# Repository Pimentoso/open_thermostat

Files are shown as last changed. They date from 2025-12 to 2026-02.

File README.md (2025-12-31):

# open_thermostat

A lightweight, open-source thermostat controller. Based on Lolin S2 mini board

## Quickstart

Install
```bash
git clone https://github.com/your-org/open_thermostat.git
cd open_thermostat
python -m venv .venv
source .venv/bin/activate
esphome run open_thermostat.yaml
```

## TODO

- Add 4.7k resistor on temp sensor
- Change button pin to GPIO1–6, GPIO14–18, GPIO21

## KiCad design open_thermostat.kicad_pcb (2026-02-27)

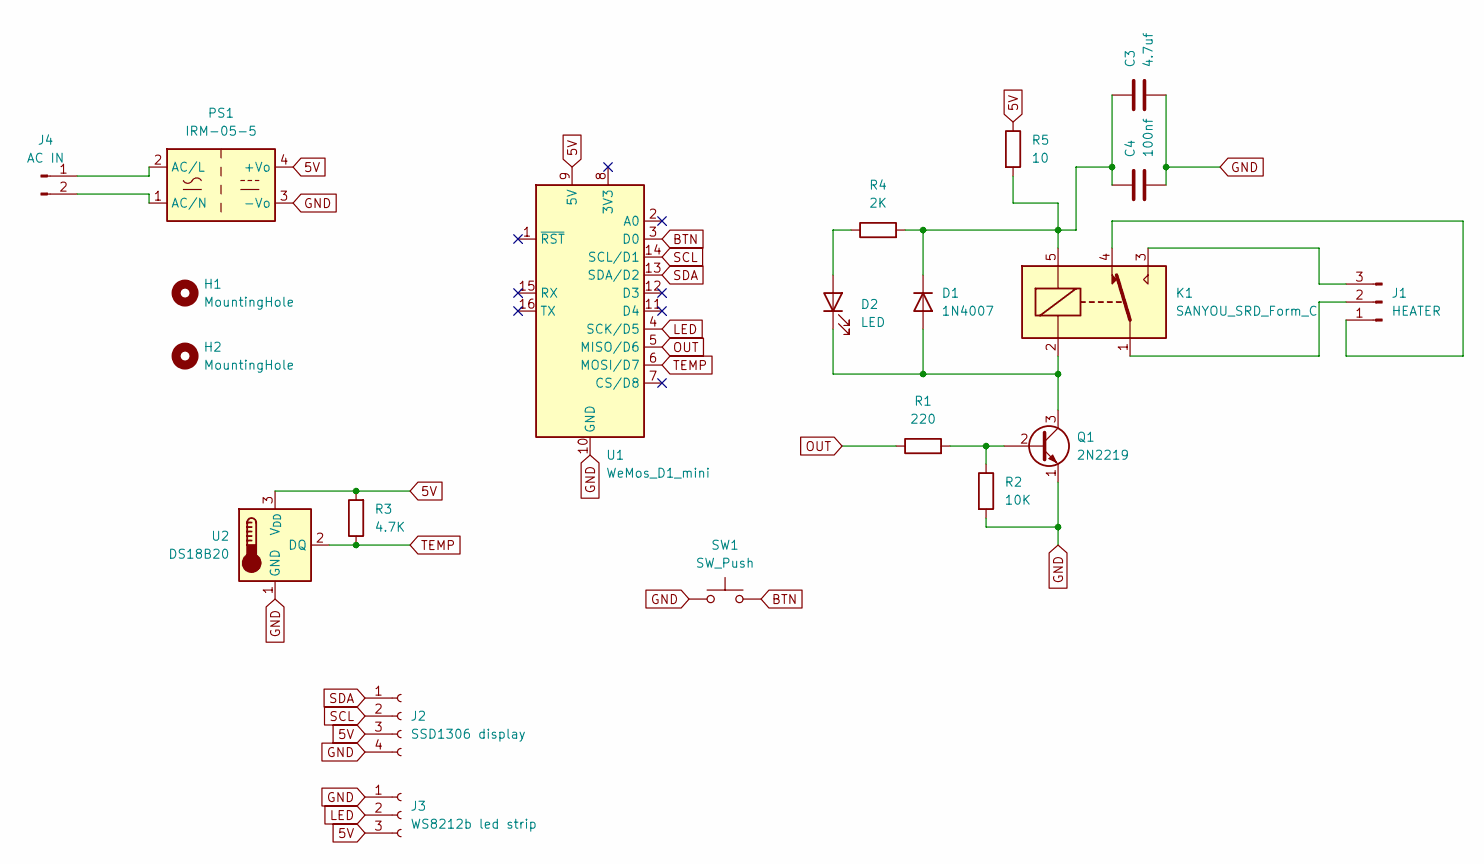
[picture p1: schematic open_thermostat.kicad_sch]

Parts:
C3: 4.7uf; C_1206_3216Metric_Pad1.33x1.80mm_HandSolder
C4: 100nf; C_1206_3216Metric_Pad1.33x1.80mm_HandSolder
D1: 1N4007; D_DO-41_SOD81_P10.16mm_Horizontal
D2: LED; LED_D5.0mm
H1, H2: MountingHole; MountingHole_4.3mm_M4
J1: HEATER; TerminalBlock_MetzConnect_Type094_RT03503HBLU_1x03_P5.00mm_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
J2: SSD1306 display; JST_XH_B4B-XH-A_1x04_P2.50mm_Vertical
J3: WS8212b led strip; JST_XH_B3B-XH-A_1x03_P2.50mm_Vertical
J4: AC IN; TerminalBlock_MetzConnect_Type094_RT03502HBLU_1x02_P5.00mm_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
K1: SANYOU_SRD_Form_C; Relay_SPDT_SANYOU_SRD_Series_Form_C
PS1: IRM-05-5; 220v AC to 5v DC Transformer
Q1: 2N2219; SOT-23_Handsoldering
R1: 220; R_1206_3216Metric_Pad1.30x1.75mm_HandSolder
R2: 10K; R_1206_3216Metric_Pad1.30x1.75mm_HandSolder
R3: 4.7K; R_1206_3216Metric_Pad1.30x1.75mm_HandSolder
R4: 2K; R_1206_3216Metric_Pad1.30x1.75mm_HandSolder
R5: 10; R_1206_3216Metric_Pad1.30x1.75mm_HandSolder
SW1: SW_Push; SW_Push_1P1T_NO_6x6mm_H9.5mm
U1: WeMos_D1_mini; WEMOS_D1_mini_light
U2: DS18B20; TO-92_Inline

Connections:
5V: J2.3, J3.3, PS1.4 (+Vo), R3.2, R5.1, U1.9 (5V), U2.3 (V_{DD})
BTN: SW1.2, U1.3 (D0)
GND: C3.1, C4.1, J2.4, J3.1, PS1.3 (-Vo), Q1.1 (E), R2.2, SW1.1, U1.10 (GND), U2.1 (GND)
LED: J3.2, U1.4 (SCK/D5)
unnamed: D1.2 (A), D2.1 (K), K1.2, Q1.3 (C)
unnamed: C3.2, C4.2, D1.1 (K), K1.5, R4.2, R5.2
unnamed: D2.2 (A), R4.1
unnamed: J1.1, K1.4
unnamed: J1.2, K1.1
unnamed: J1.3, K1.3
unnamed: J4.1, PS1.2 (AC/L)
unnamed: J4.2, PS1.1 (AC/N)
unnamed: Q1.2 (B), R1.2, R2.1
OUT: R1.1, U1.5 (MISO/D6)
SCL: J2.2, U1.14 (SCL/D1)
SDA: J2.1, U1.13 (SDA/D2)
TEMP: R3.1, U1.6 (MOSI/D7), U2.2 (DQ)

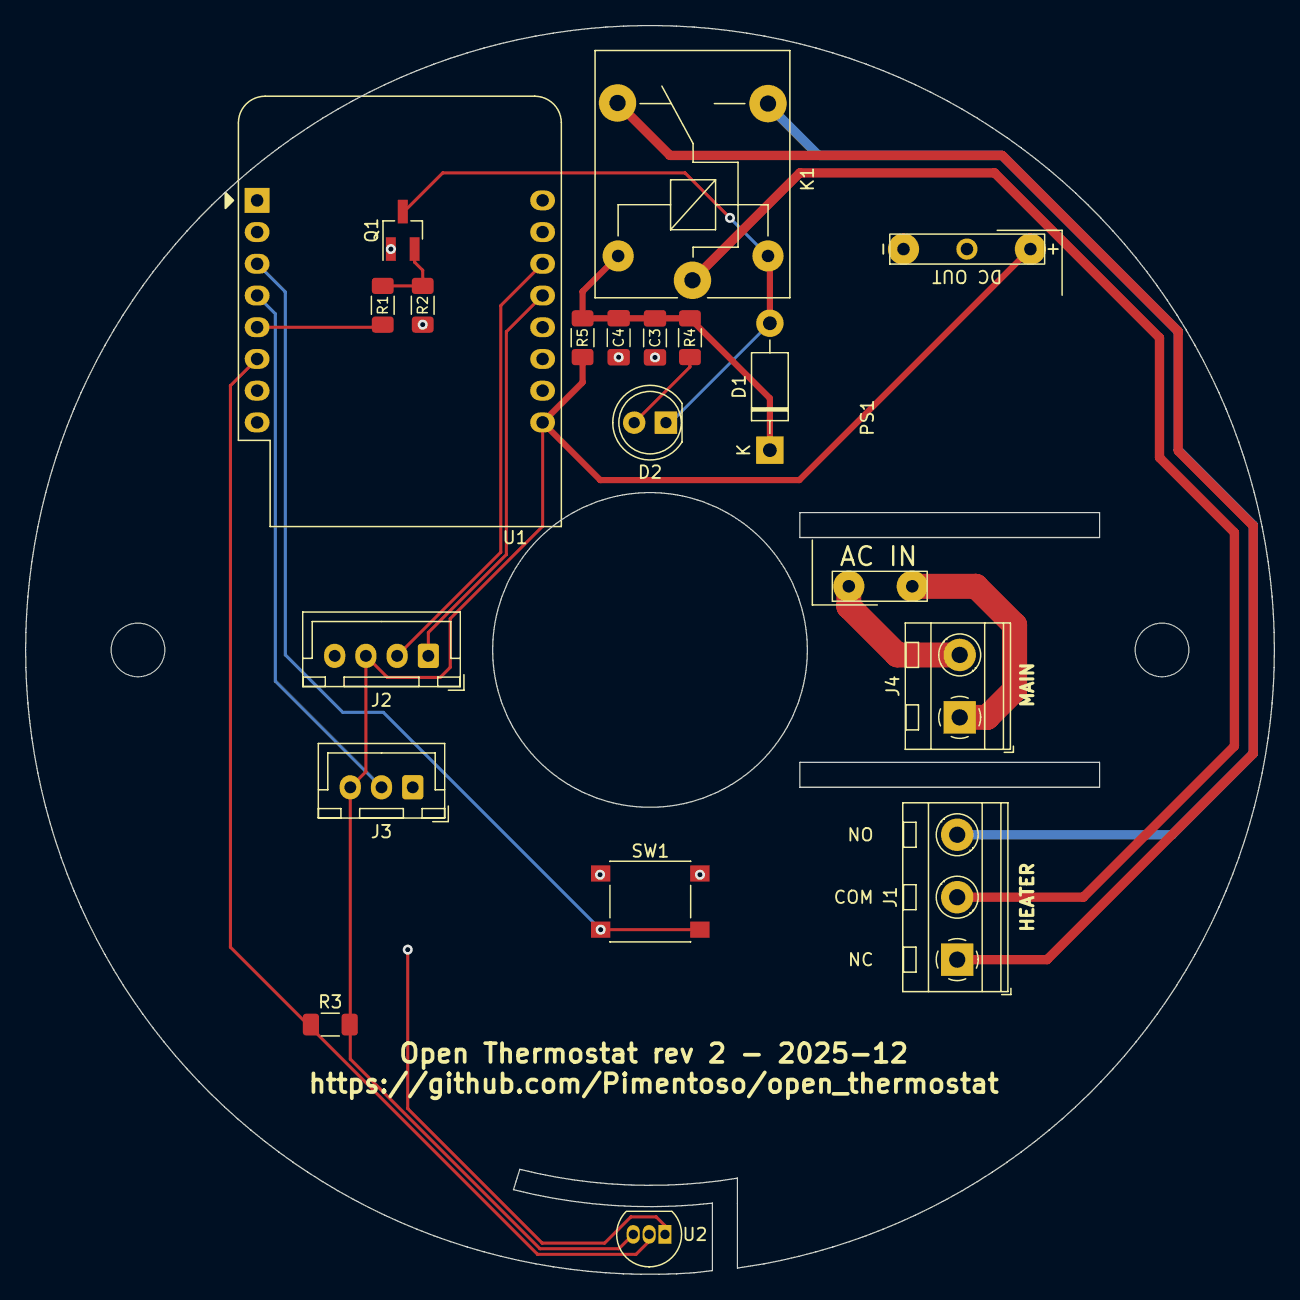
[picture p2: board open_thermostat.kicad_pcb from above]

Board: 2 copper layers, 100.0 x 100.0 mm, 21 parts (0 on the bottom side), 17 nets.

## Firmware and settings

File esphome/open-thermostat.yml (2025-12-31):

substitutions:
  device_name: open-thermostat
  day_temp: "19.5"
  night_temp: "17.0"

esphome:
  name: ${device_name}

esp32:
  board: lolin_s2_mini
  variant: esp32s2
  framework:
    type: esp-idf

preferences:
  flash_write_interval: 10min

wifi:
  ssid: !secret wifi_ssid
  password: !secret wifi_password
  power_save_mode: none
  ap:
    ssid: ${device_name} hotspot
    password: !secret hotspot_password

captive_portal:

logger:
  baud_rate: 0

api:

ota:
  platform: esphome

i2c:
  scl: GPIO35
  sda: GPIO33
  scan: true
  
one_wire:
- platform: gpio
  pin: GPIO12
  
switch:
- platform: gpio
  pin: GPIO9
  name: "${device_name}-relay"
  id: relay_caldaia
  restore_mode: RESTORE_DEFAULT_OFF
  on_turn_on:
    - delay: 200ms
    - light.turn_on:
        id: rgb_leds
        red: 100%
        green: 40%
        blue: 0%
        effect: circle
  on_turn_off:
    - delay: 200ms
    - light.turn_off: rgb_leds
  
binary_sensor:
- platform: gpio
  pin:
    number: GPIO11
    mode: INPUT_PULLUP
    inverted: true
  name: "${device_name}-toggle"
  id: toggle_button
  internal: true
  on_press:
    - switch.toggle: relay_caldaia
  filters:
    - delayed_on_off: 50ms

sensor:
- platform: dallas_temp
  name: "${device_name}-temperature"
  id: temperature_sensor
  device_class: temperature
  state_class: measurement
  unit_of_measurement: "°C"
  accuracy_decimals: 1
  update_interval: 30s
  filters:
    - sliding_window_moving_average:
        window_size: 12
        send_every: 4
        send_first_at: 1

button:
- platform: restart
  name: "${device_name}-restart"
  entity_category: config
- platform: factory_reset
  name: "${device_name}-factory-reset"
  id: Reset
  entity_category: config
- platform: safe_mode
  name: "${device_name}-safe-mode"
  internal: false
  entity_category: config

light:
- platform: esp32_rmt_led_strip
  pin: GPIO7
  name: "${device_name}-leds"
  id: rgb_leds
  chipset: WS2812
  rgb_order: GRB
  num_leds: 24
  color_correct: [25%, 25%, 25%]
  effects:
  - addressable_lambda:
      name: circle
      update_interval: 500ms
      lambda: |-
        static int pos = 0;
        int len = it.size();
        // clear strip
        for (int i = 0; i < len; i++) it[i] = Color(0, 0, 0);
        // light 3 consecutive LEDs (unidirectional)
        for (int j = 0; j < 3; j++) {
          it[(pos + j) % len] = Color(255, 100, 0);
        }
        pos = (pos + 1) % len;
- platform: status_led
  name: "${device_name}-status-led"
  icon: "mdi:alarm-light"
  restore_mode: ALWAYS_OFF
  pin:
    number: GPIO15
    inverted: false

globals:
- id: jitter
  type: int
  restore_value: no
  initial_value: '0'
- id: jitter_temp
  type: int
  restore_value: no
  initial_value: '10'

# Anti burn-in
interval:
- interval: 3s
  then:
    - lambda: |-
        id(jitter) = (id(jitter) + 1) % 3;
        id(jitter_temp) = (id(jitter_temp) + 1) % 20;

display:
- platform: ssd1306_i2c
  id: oled_display
  model: SSD1306 128x64
  address: 0x3C
  rotation: 180
  pages:
    - id: display_page_1
      lambda: |-
        it.fill(COLOR_OFF);
        const int xoff = id(jitter);
        const int xoff_temp = id(jitter_temp);

        // TIME — small, top-left
        it.strftime(2 + xoff, 2, id(font_sm), TextAlign::TOP_LEFT, "%H:%M", id(display_time).now());

        // TEMP — big, centered
        if (id(temperature_sensor).has_state()) {
          it.printf(54 + xoff_temp, 15, id(font_xl), TextAlign::TOP_CENTER, "%.1f", id(temperature_sensor).state);
        } else {
          it.printf(54 + xoff_temp, 15, id(font_xl), TextAlign::TOP_CENTER, "--.-");
        }

        // HEATER ICON(S) — show when relay is ON
        if (id(relay_caldaia).state) {
        // if (true) {
          it.image(xoff_temp-2, 24, id(fire));
          it.image(92 + xoff_temp, 24, id(fire));
        }


font:
- file: font/retrogaming.ttf
  id: font_sm
  size: 11
  glyphs: '!"%*()+=,-_.:0123456789ABCDEFGHIJKLMNOPQRSTUVWXYZ abcdefghijklmnopqrstuvwxyz'
- file: font/retrogaming.ttf
  id: font_xl
  size: 28
  glyphs: '!"%*()+=,-_.:0123456789ABCDEFGHIJKLMNOPQRSTUVWXYZ abcdefghijklmnopqrstuvwxyz'

image:
- file: mdi:fire
  id: fire
  resize: 22x22
  type: BINARY

time:
- platform: homeassistant
  id: display_time

climate:
- platform: thermostat
  name: Termostato Caldaia
  sensor: temperature_sensor
  on_boot_restore_from: memory
  min_heating_off_time: 30s
  min_heating_run_time: 30s
  min_idle_time: 30s
  heat_deadband: 0.1 °C
  heat_overrun: 0.5 °C
  heat_action:
    - switch.turn_on: relay_caldaia
  idle_action:
    - switch.turn_off: relay_caldaia
  off_mode:
    - switch.turn_off: relay_caldaia
  visual:
    min_temperature: 15
    max_temperature: 25
    temperature_step: 0.1
  default_preset: Home
  preset:
    - name: Home
      default_target_temperature_low: ${day_temp}
      mode: heat
    - name: Night
      default_target_temperature_low: ${night_temp}
      mode: heat

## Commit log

2025-12-23 pcb fixes
    [open_thermostat.kicad_pcb, open_thermostat.kicad_sch]
2025-12-26 add light turn on delay to avoid boot loop
    weird issue about the board failing to boot when the lights were on during reset. It tried to power them on when the component was not fully ready. Log:
    Guru Meditation Error: Core 0 panic'ed (LoadProhibited). Exception was unhandled.
    WARNING Decoded 0x4011bfa7: esphome::light::LightState::get_output() const at /Users/miche/Documents/Github/open_thermostat/esphome/.esphome/build/open-thermostat/src/esphome/components/light/light_state.cpp:163
    [open-thermostat.yml]
2025-12-31 add status led and fix temp values
    [open-thermostat.yml]
2026-02-27 wip new version
    [open_thermostat.kicad_pcb, open_thermostat.kicad_sch]
